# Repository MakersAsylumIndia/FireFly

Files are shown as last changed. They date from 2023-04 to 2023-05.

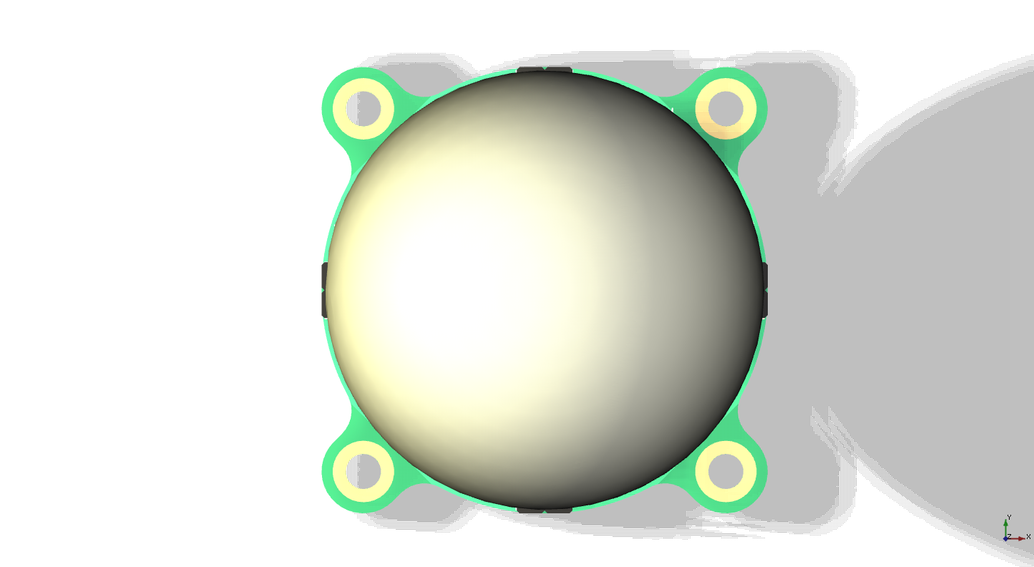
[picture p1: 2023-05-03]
fabricate/renders/firefly_v1_06.png

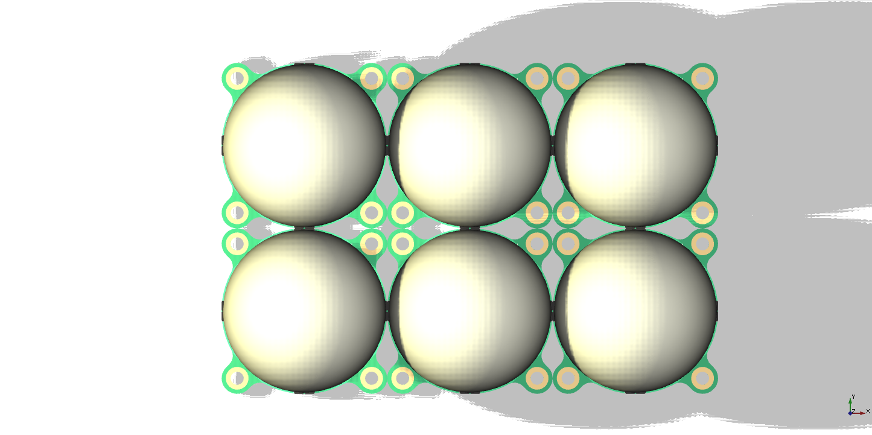
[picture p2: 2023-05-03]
fabricate/renders/firefly_v1_grid_02.png

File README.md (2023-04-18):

# FireFly
This circuit simulates a firefly with a tiny microcontroller. If put together with other fireflies, they will flash randomly. But after some time they will start to interact with each other and the flashes will start synchronize until all fireflies flash at once. Based on https://github.com/tinkerlog/fireflies

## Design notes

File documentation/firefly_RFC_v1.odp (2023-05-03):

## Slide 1

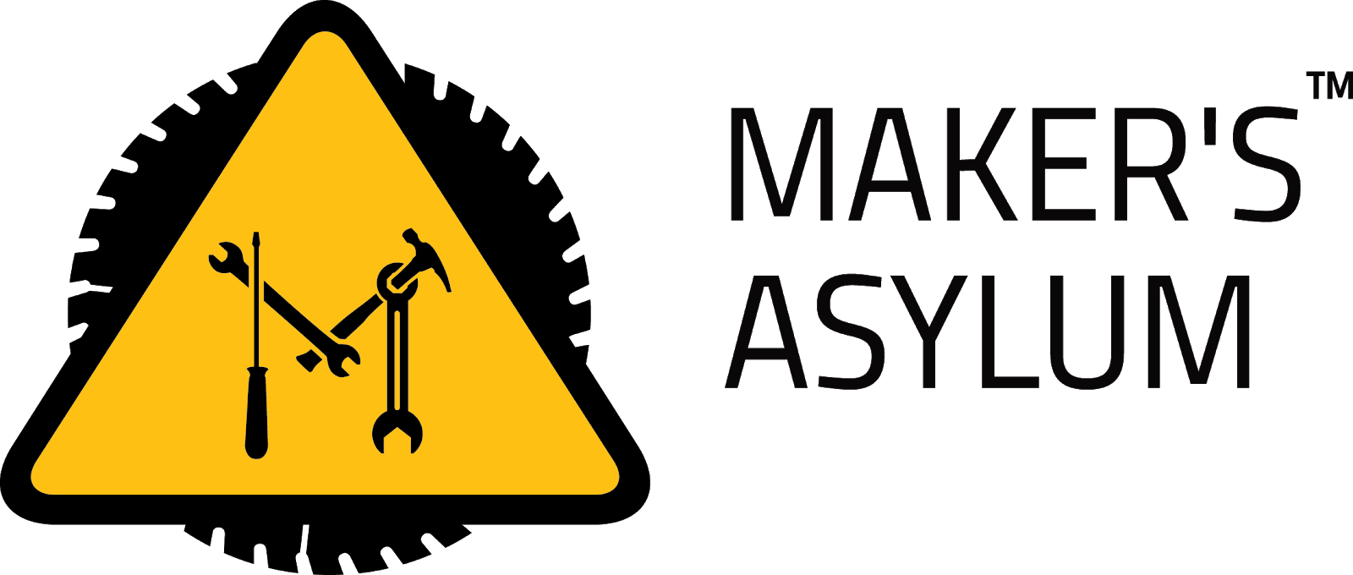
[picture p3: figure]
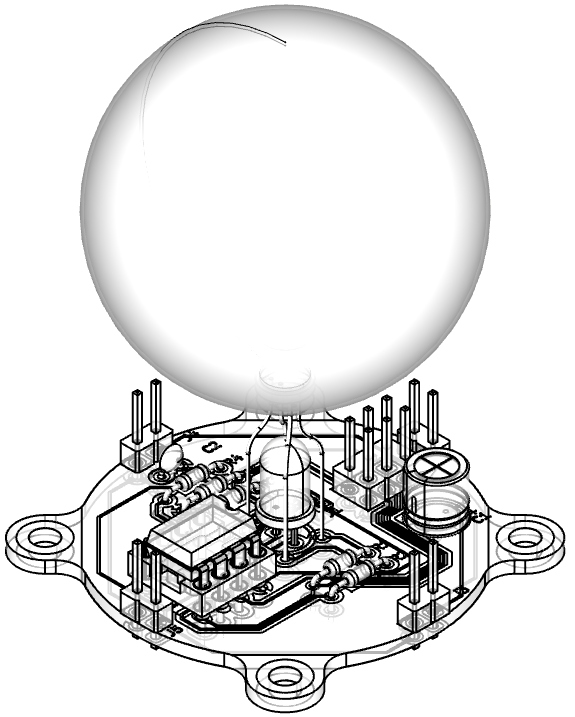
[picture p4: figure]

“FireFly” v1

Collaborative Art

Installation

(Proposed project for Innov School Practicum)

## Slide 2

Requirements

- Complexity level – between MODERATE and SIMPLE
- Must include elements of
  - Electronics (soldering)
  - Arduino (programming)
  - Rapid prototyping (3D printing / laser cutting)
  - Collaboration
- Powered by 5V – power bank, wall adapter, charger etc
- Expandable / Hackable

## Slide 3

Schematic

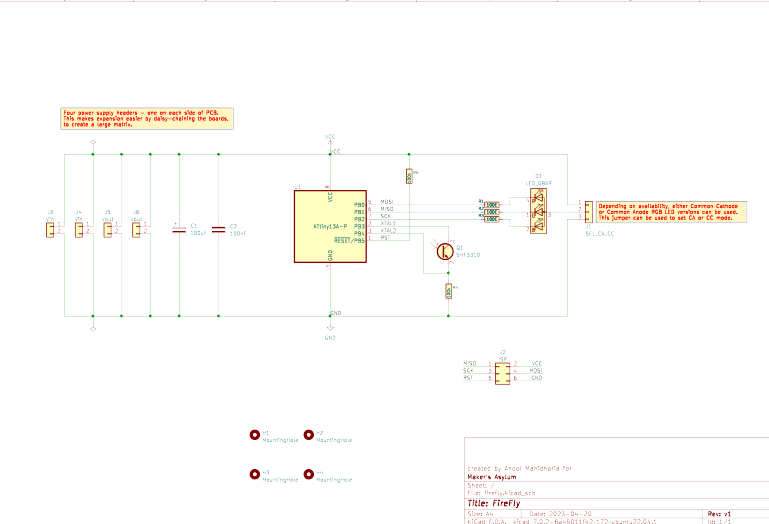
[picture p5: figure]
SVG Image created as firefly.svg date 2023/04/20 13:13:49 Image generated by Eeschema-SVG

Components:

- ATtiny13
- RGB LED, 5mm, CA/CC
- Light Sensor
- 5 resistors
- 2 capacitors
- Header pins
- Header pin shorting links
- PCB
- Ping-Pong ball

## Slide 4

Options

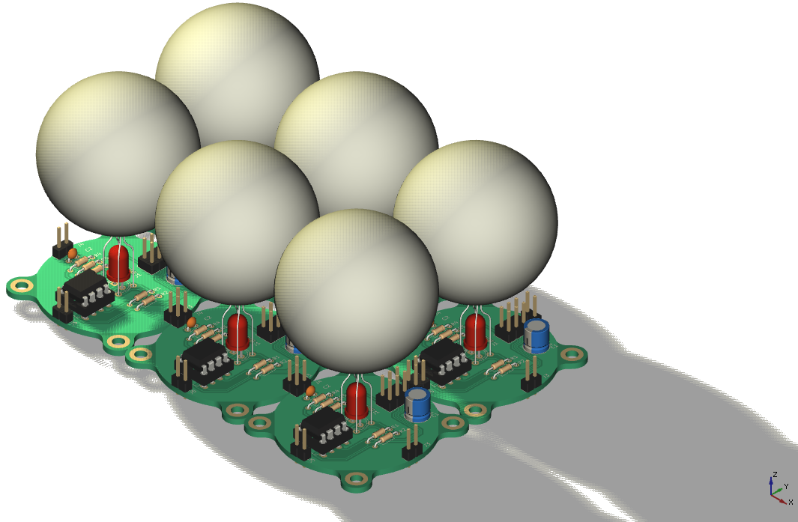
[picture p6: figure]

Optional upgrades

(not included in kit)

- The circuit is complete by itself, but this is a collaborative project.
- Multiple PCB’s are daisy chained together.
- Each flashes randomly, but after some time, they start synchronizing their color and flashing rate.
- The whole Practicum class can mount all their FireFlies on a MDF or Acrylic board.

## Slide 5

PCB Render

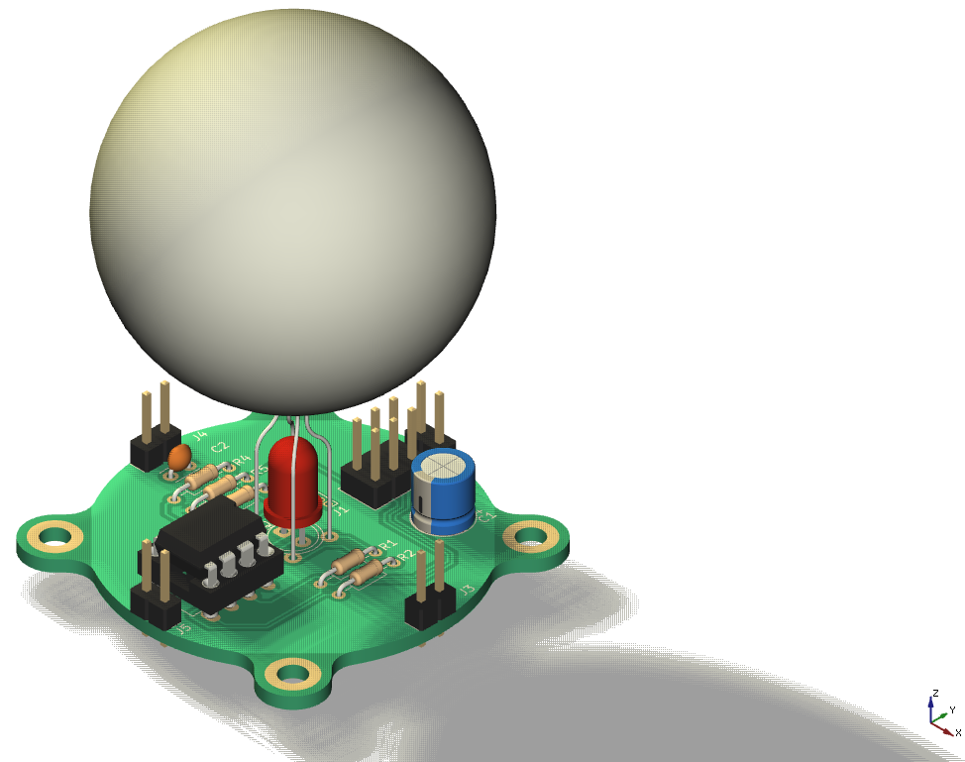
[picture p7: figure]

Power headers, x4

SPI header,

programming

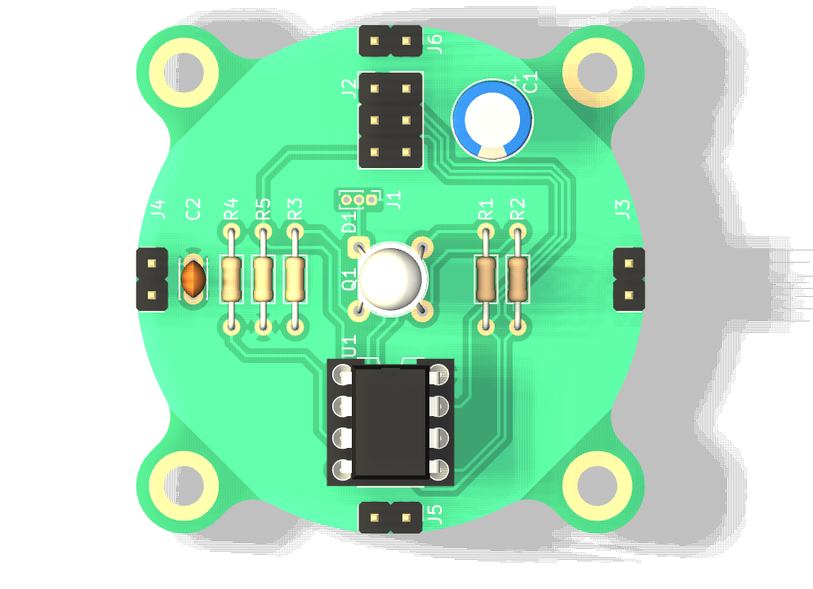
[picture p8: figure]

RGB LED

Ping-Pong Ball

diffuser

Light Sensor under RGB LED

ATtiny13

Mount holes

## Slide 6

PCB Front / Bottom view

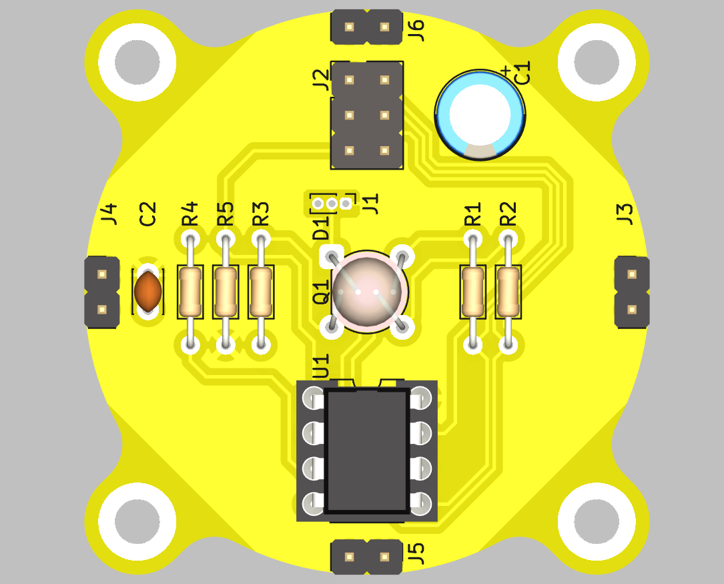
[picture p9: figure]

- All parts are mounted on front side.
- All parts are through hole so soldering is easy

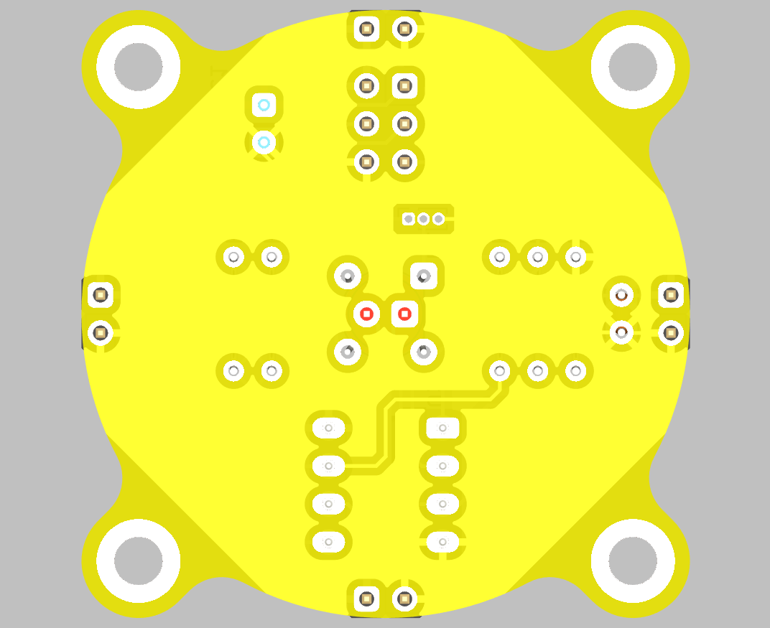
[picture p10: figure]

- Add some funky text / graphics on bottom

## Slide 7

PCB Side view

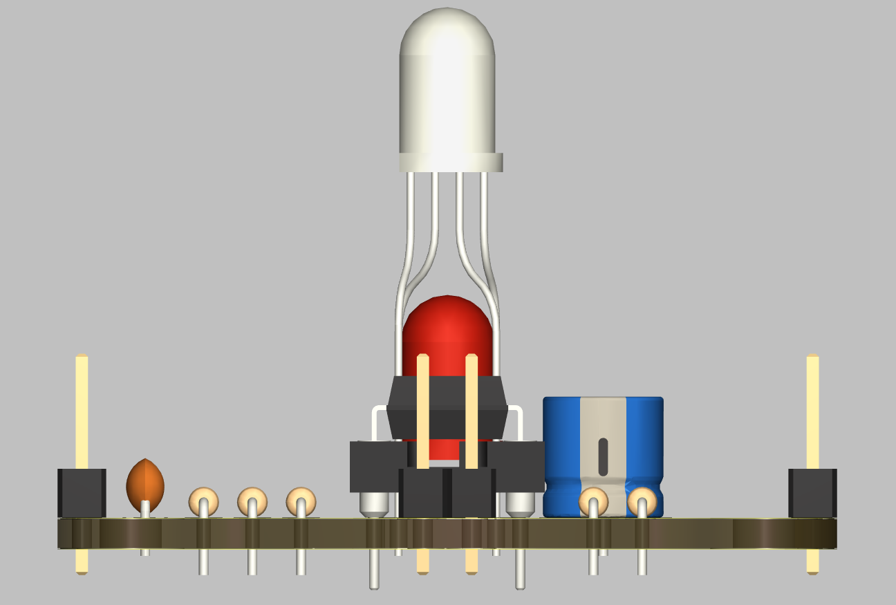
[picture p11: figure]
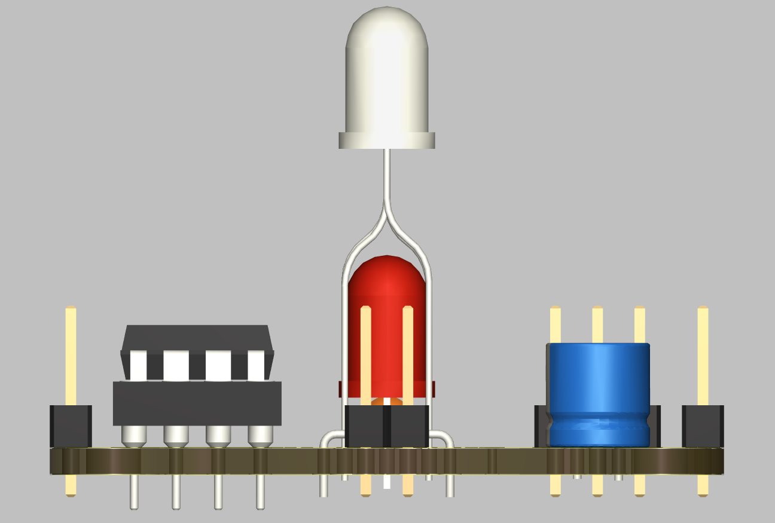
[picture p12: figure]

- Side views of the PCB.

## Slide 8

1.6” (40.6 mm)

1.6” (40.6 mm)

PCB dimensions

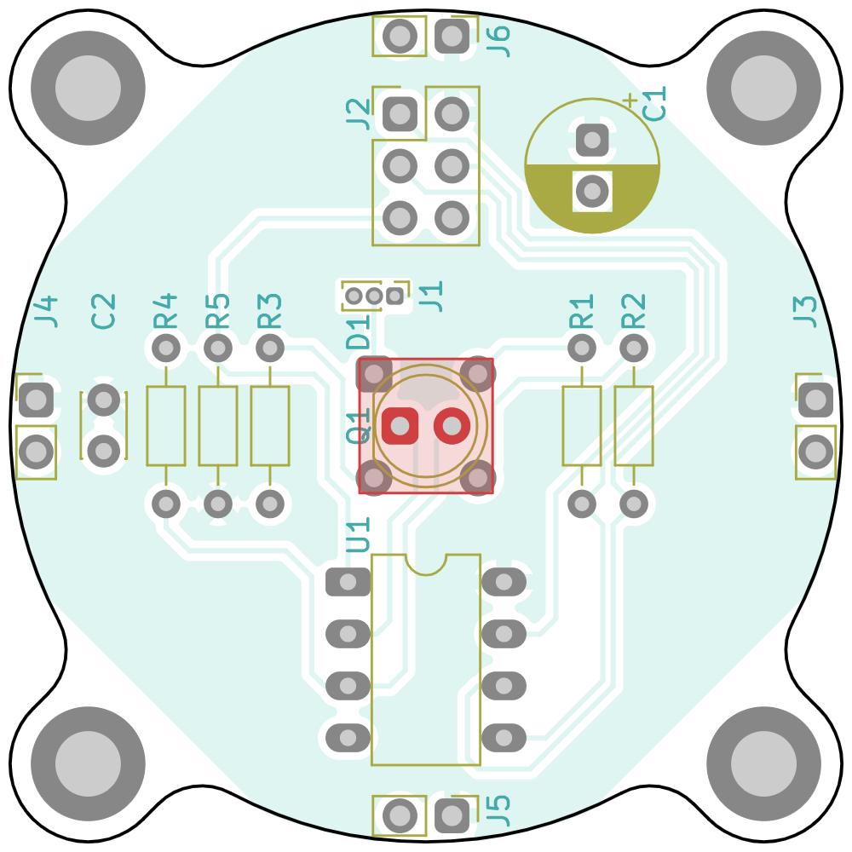
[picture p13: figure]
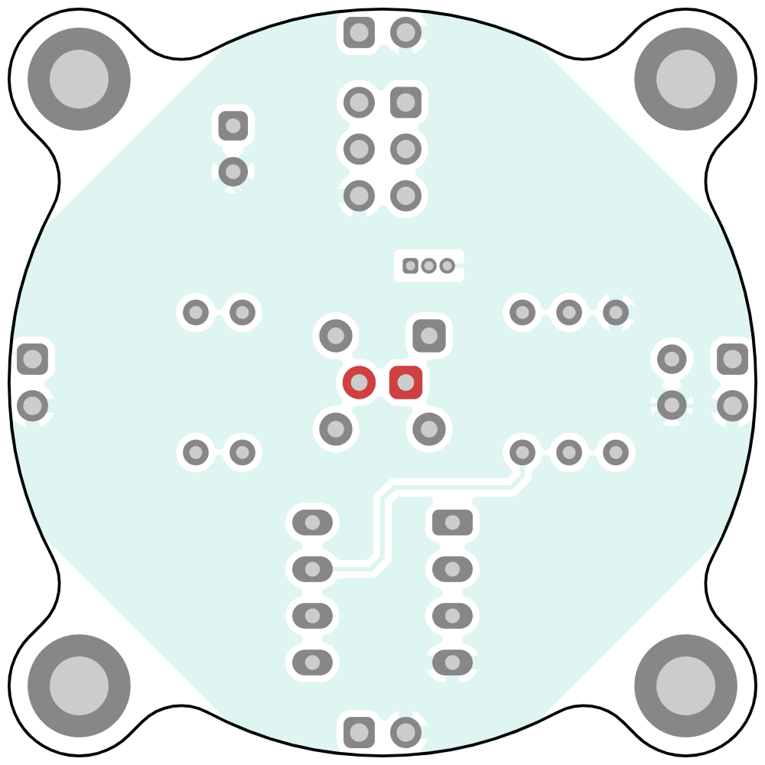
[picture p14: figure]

1.6 inches x 1.6 inches

(40.6 mm x 40.6 mm)

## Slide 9

Installation

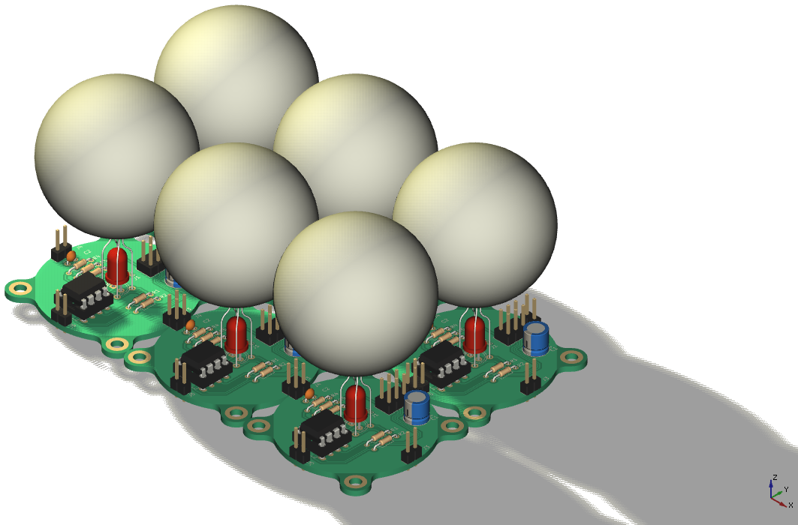
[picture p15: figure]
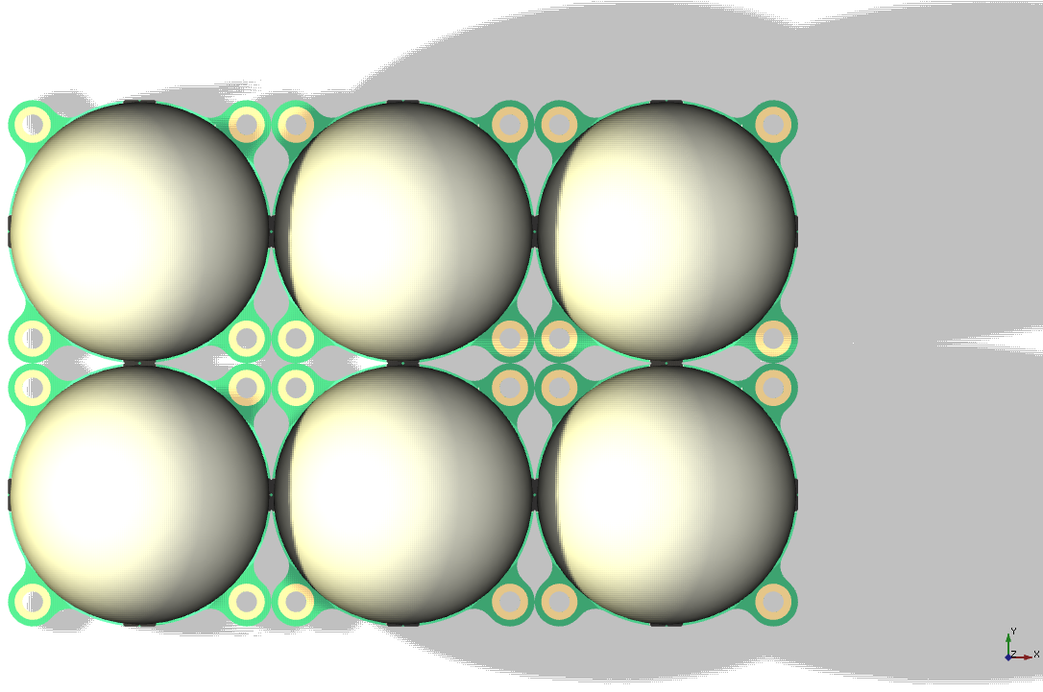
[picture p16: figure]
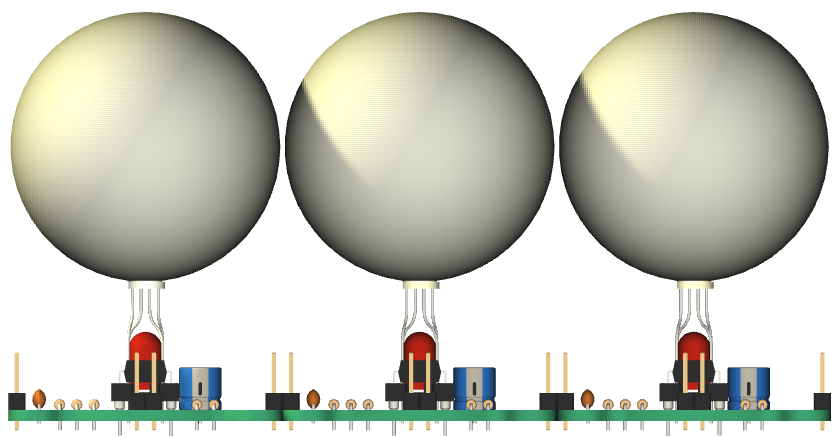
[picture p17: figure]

Individual PCB’s are connected to each other using header pin shorting links. Connections are just for power supply.

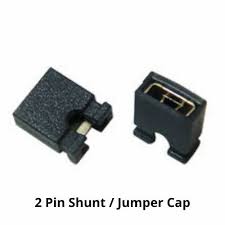
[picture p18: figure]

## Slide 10

NOTES

- Derived from:
  - https://www.instructables.com/Synchronizing-Fireflies/
  - https://tinkerlog.com/howto/synchronizing-firefly-how-to/
  - https://github.com/tinkerlog/fireflies
- Microcontroller is ATtiny13. Running Arduino on it will take some effort.
- Original code is available as a ‘Makefile”. This will have to be reverse engineered to work as Arduino code.
- More details on algorithm, code etc on the Instructables page

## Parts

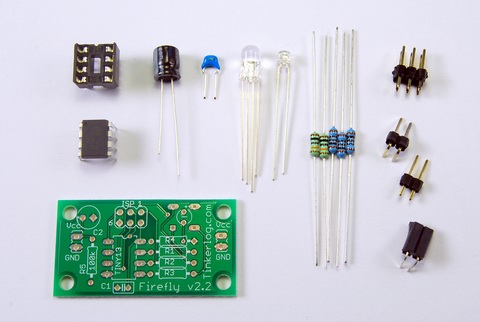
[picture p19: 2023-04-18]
datasheets/fireflies_parts.jpg

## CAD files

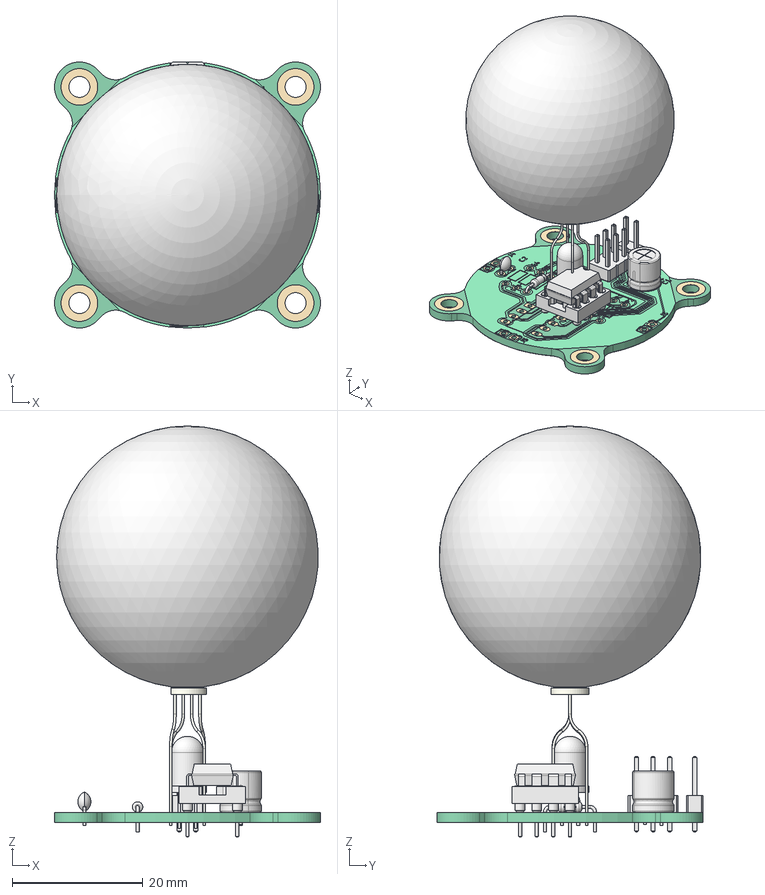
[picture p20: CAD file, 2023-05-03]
fabricate/firefly_v1_grid.FCStd
40.6 x 40.6 x 62.8 mm
DIP_8_W762mm_Socket_sp
DIP_8_W762mm_Socket_sp001
Pcb_3165
R3_R_Axial_DIN0204_L36mm_D16mm_P762mm_Horizontal_c94ef6852790
J6_PinHeader_1x02_P254mm_Vertical_1fb545e78c9a
J2_PinHeader_2x03_P254mm_Vertical_75255a230ba9
C1_CP_Radial_D63mm_P250mm_7c2f516e95ce
Q1_LED_D5.0mm_18f4e428e7b4
C2_C_Disc_D30mm_W20mm_P250mm_075f2212bfdc
topTracks_3165
botTracks_3165
topPads_3165
botPads_3165
topSilks_3a64
topZones_3165
botZones_3165

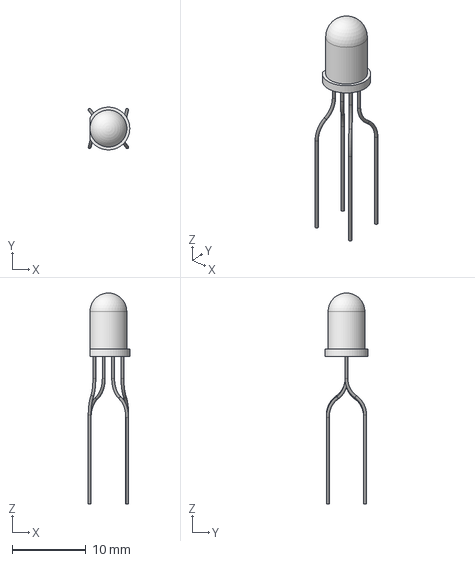
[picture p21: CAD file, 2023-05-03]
fabricate/footprints/LED_5mm_RGB-Fusion.step
5.65 x 5.79 x 28.6 mm

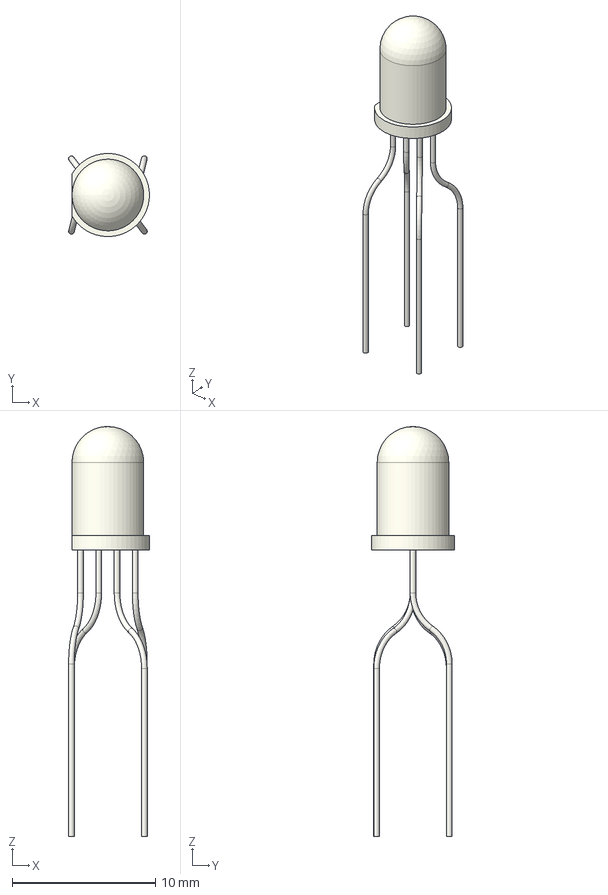
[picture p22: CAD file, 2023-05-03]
kicad_v1/firefly/3d_models/LED_D5.0mm-4_RGB_Square_Pins.step
5.65 x 5.79 x 28.6 mm

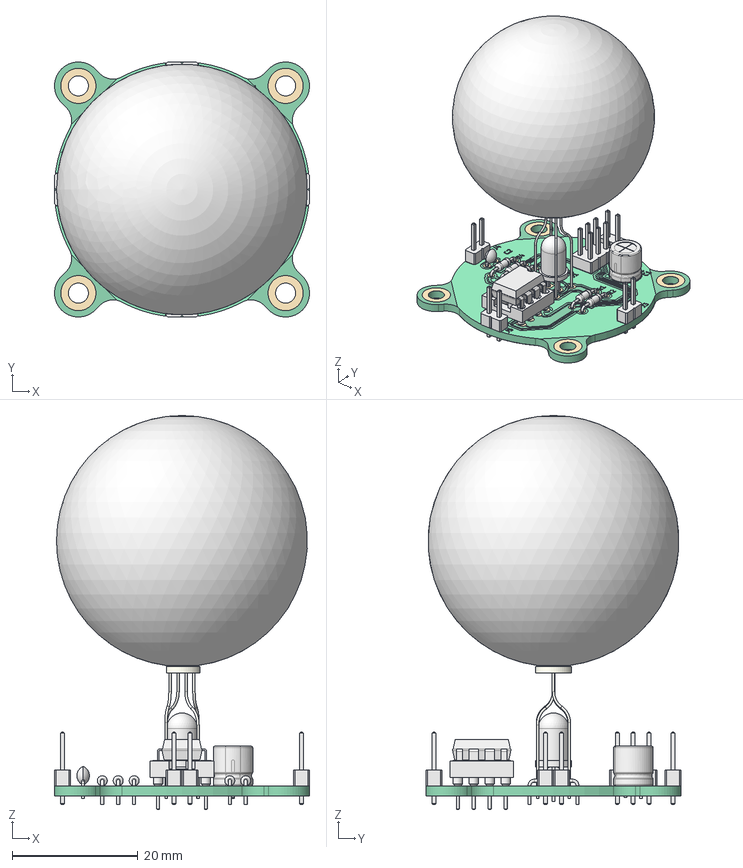
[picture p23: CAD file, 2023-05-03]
fabricate/firefly_v1.FCStd
40.6 x 40.6 x 62.8 mm
Pcb_3165
topPads_3165
topTracks_3165
topZones_3165
botPads_3165
botTracks_3165
botZones_3165
topSilks_3a64
R3_R_Axial_DIN0204_L36mm_D16mm_P762mm_Horizontal_c94ef6852790 x 5
J6_PinHeader_1x02_P254mm_Vertical_1fb545e78c9a x 4
J2_PinHeader_2x03_P254mm_Vertical_75255a230ba9
C1_CP_Radial_D63mm_P250mm_7c2f516e95ce
DIP_8_W762mm_Socket_sp
DIP_8_W762mm_Socket_sp001
Q1_LED_D5.0mm_18f4e428e7b4
C2_C_Disc_D30mm_W20mm_P250mm_075f2212bfdc

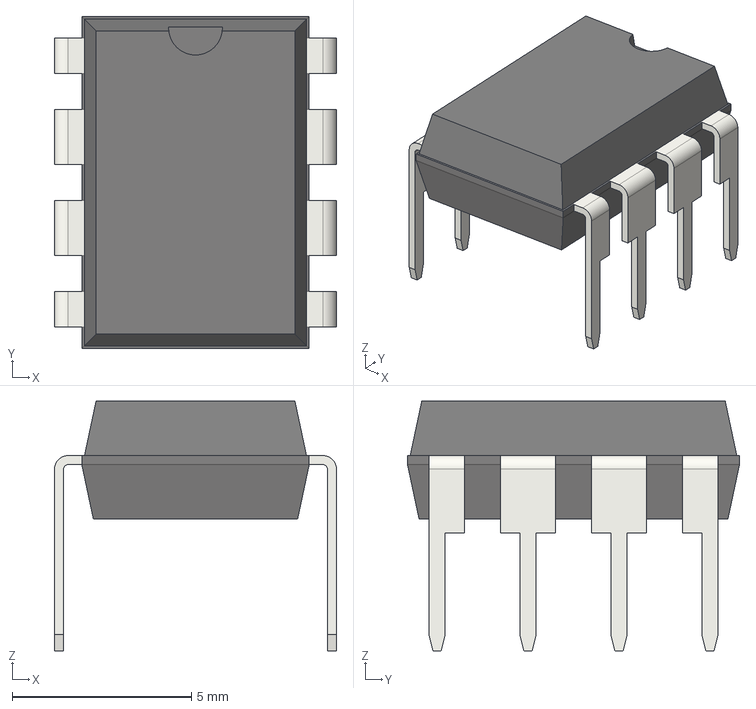
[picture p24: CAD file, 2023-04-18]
kicad_v1/firefly/3d_models/DIP-8_W7.62mm.step
7.87 x 9.27 x 6.98 mm

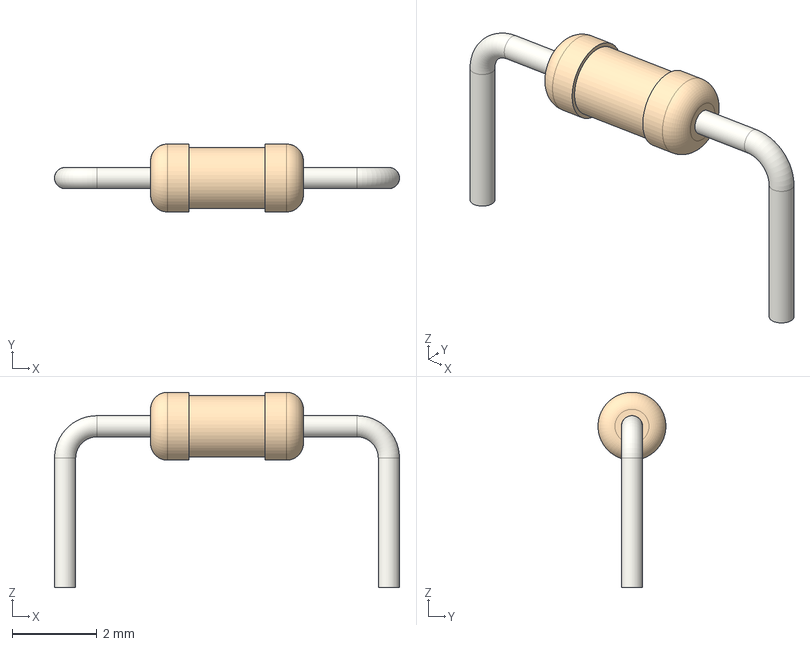
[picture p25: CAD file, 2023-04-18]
kicad_v1/firefly/3d_models/R_Axial_DIN0204_L3.6mm_D1.6mm_P7.62mm_Horizontal.step
8.12 x 1.60 x 4.60 mm

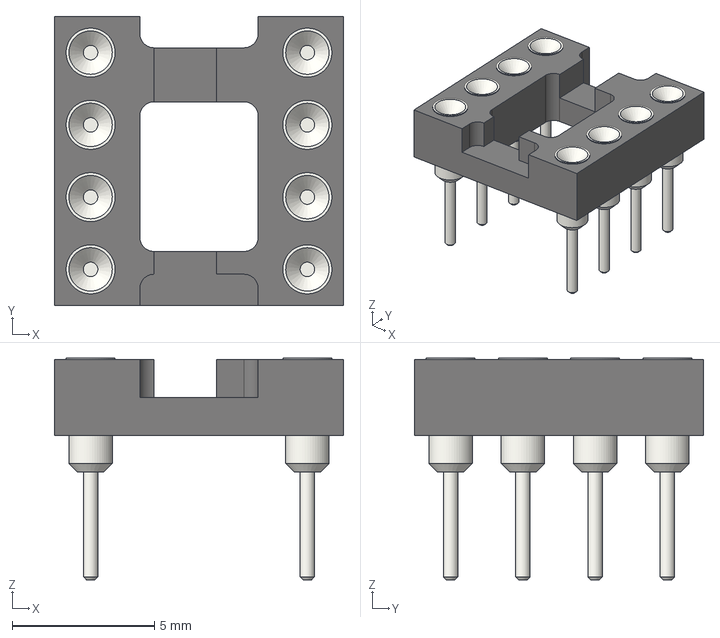
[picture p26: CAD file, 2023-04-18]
kicad_v1/firefly/3d_models/DIP-8_W7.62mm_Socket.step
10.2 x 10.2 x 7.79 mm

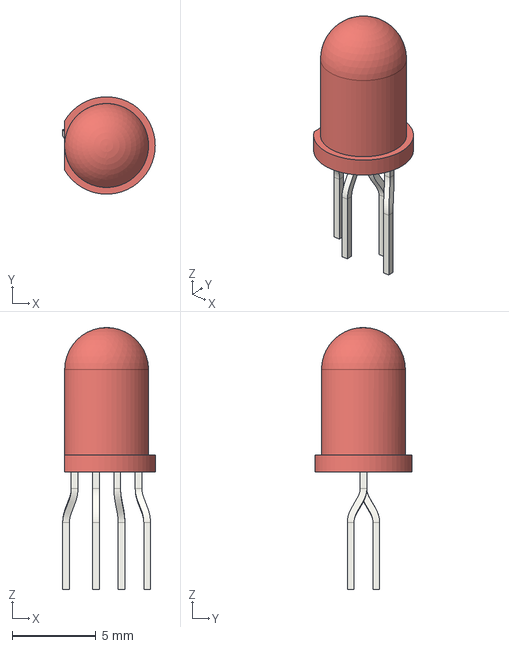
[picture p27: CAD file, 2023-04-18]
kicad_v1/firefly/3d_models/LED_D5.0mm-4_RGB_Staggered_Pins.step
5.51 x 5.79 x 15.6 mm

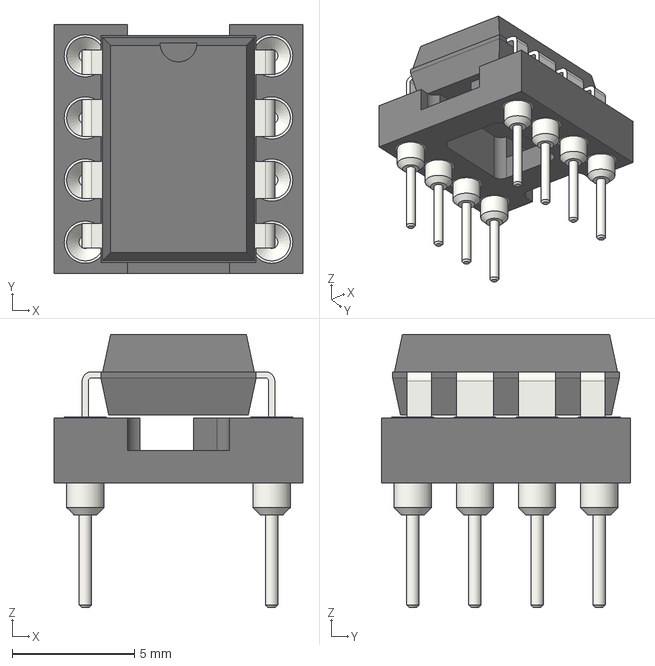
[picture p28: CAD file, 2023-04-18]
kicad_v1/firefly/3d_models/DIP_8_W762mm_Socket_chip.step
10.2 x 10.2 x 11.2 mm

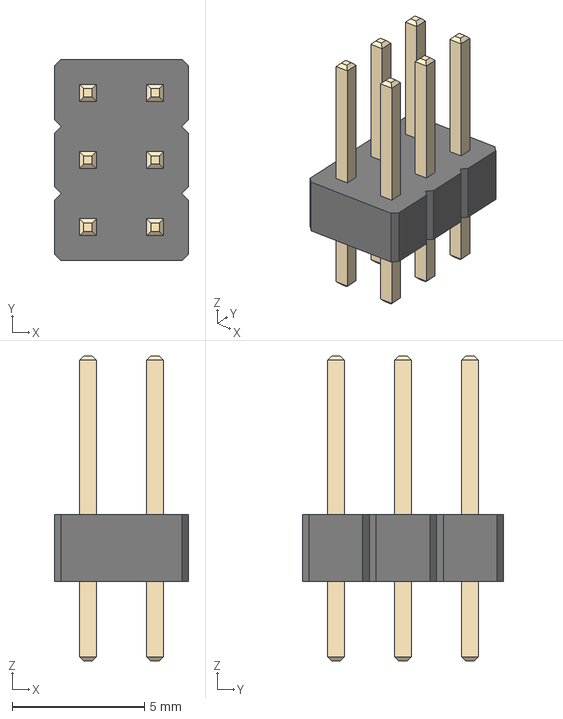
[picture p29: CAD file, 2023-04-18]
kicad_v1/firefly/3d_models/PinHeader_2x03_P2.54mm_Vertical.step
5.08 x 7.62 x 11.5 mm

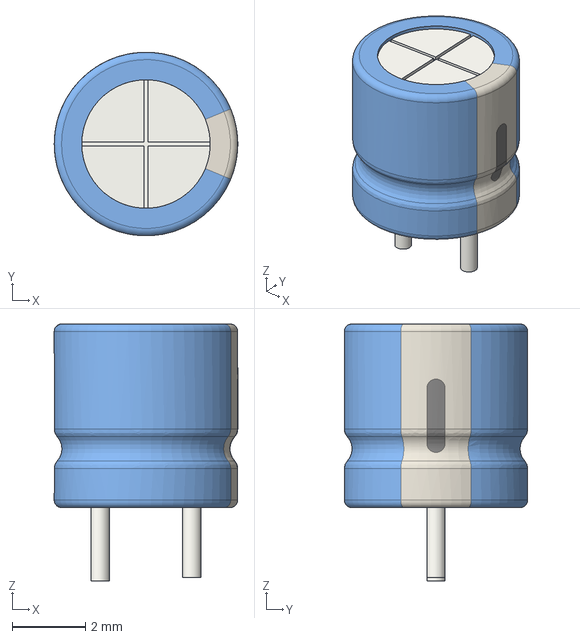
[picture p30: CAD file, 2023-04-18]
kicad_v1/firefly/3d_models/CP_Radial_D5.0mm_P2.50mm.step
5.00 x 5.00 x 7.00 mm

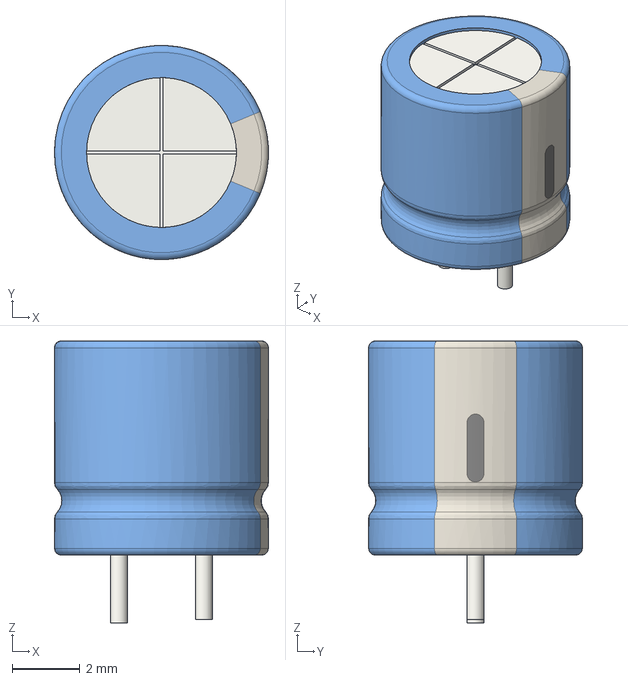
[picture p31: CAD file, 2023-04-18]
kicad_v1/firefly/3d_models/CP_Radial_D6.3mm_P2.50mm.step
6.30 x 6.30 x 8.30 mm

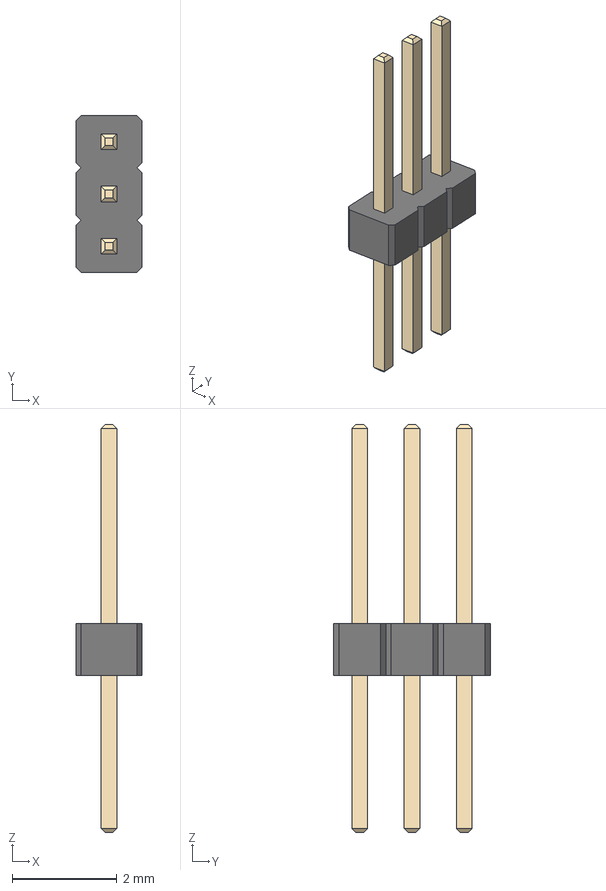
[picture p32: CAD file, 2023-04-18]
kicad_v1/firefly/3d_models/PinHeader_1x03_P1.00mm_Vertical.step
1.27 x 3.00 x 7.80 mm

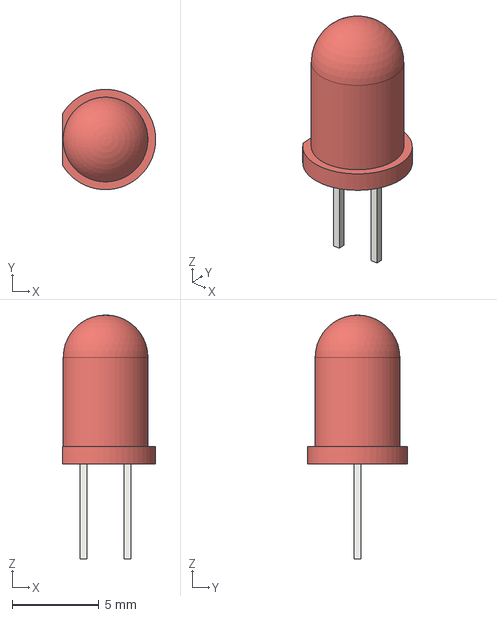
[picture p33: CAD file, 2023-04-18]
kicad_v1/firefly/3d_models/LED_D5.0mm.step
5.40 x 5.79 x 14.1 mm

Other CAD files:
fabricate/footprints/LED_5mm_RGB.step
kicad_v1/firefly/3d_models/C_Disc_D3.0mm_W2.0mm_P2.50mm.step
kicad_v1/firefly/3d_models/LED_D5.0mm-4_RGB_Staggered_Pins_raise.step
kicad_v1/firefly/3d_models/PinHeader_1x02_P2.54mm_Vertical.step
fabricate/footprints/LED_5mm_RGB.FCStd
kicad_v1/firefly/firefly-B_Silkscreen.dxf
kicad_v1/firefly/firefly-F_Silkscreen.dxf

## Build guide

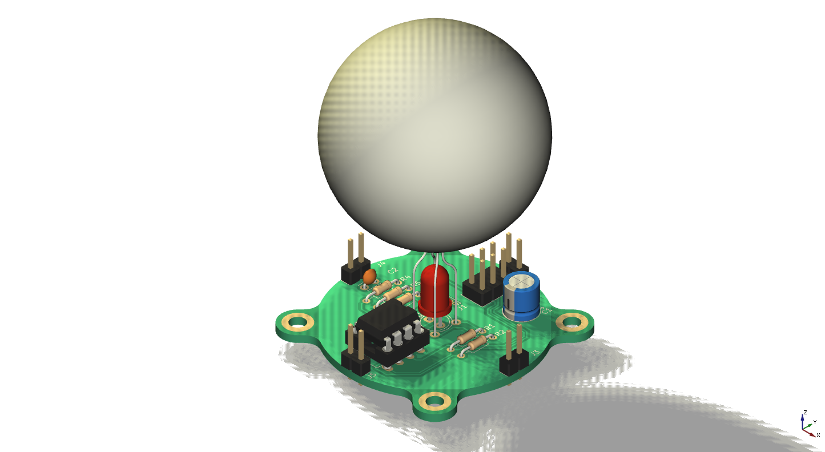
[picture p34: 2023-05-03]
fabricate/renders/firefly_v1_05.png

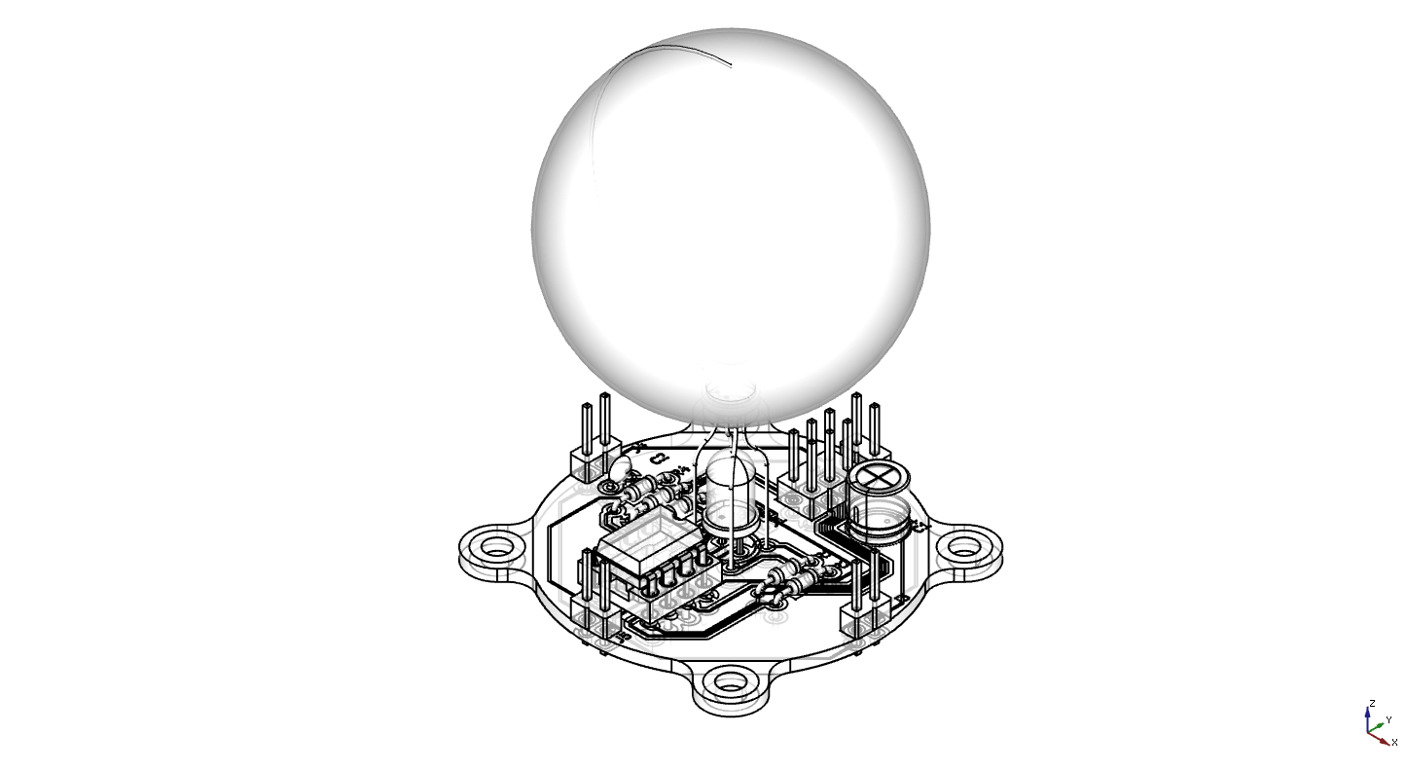
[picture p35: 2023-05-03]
fabricate/renders/firefly_v1_08.png

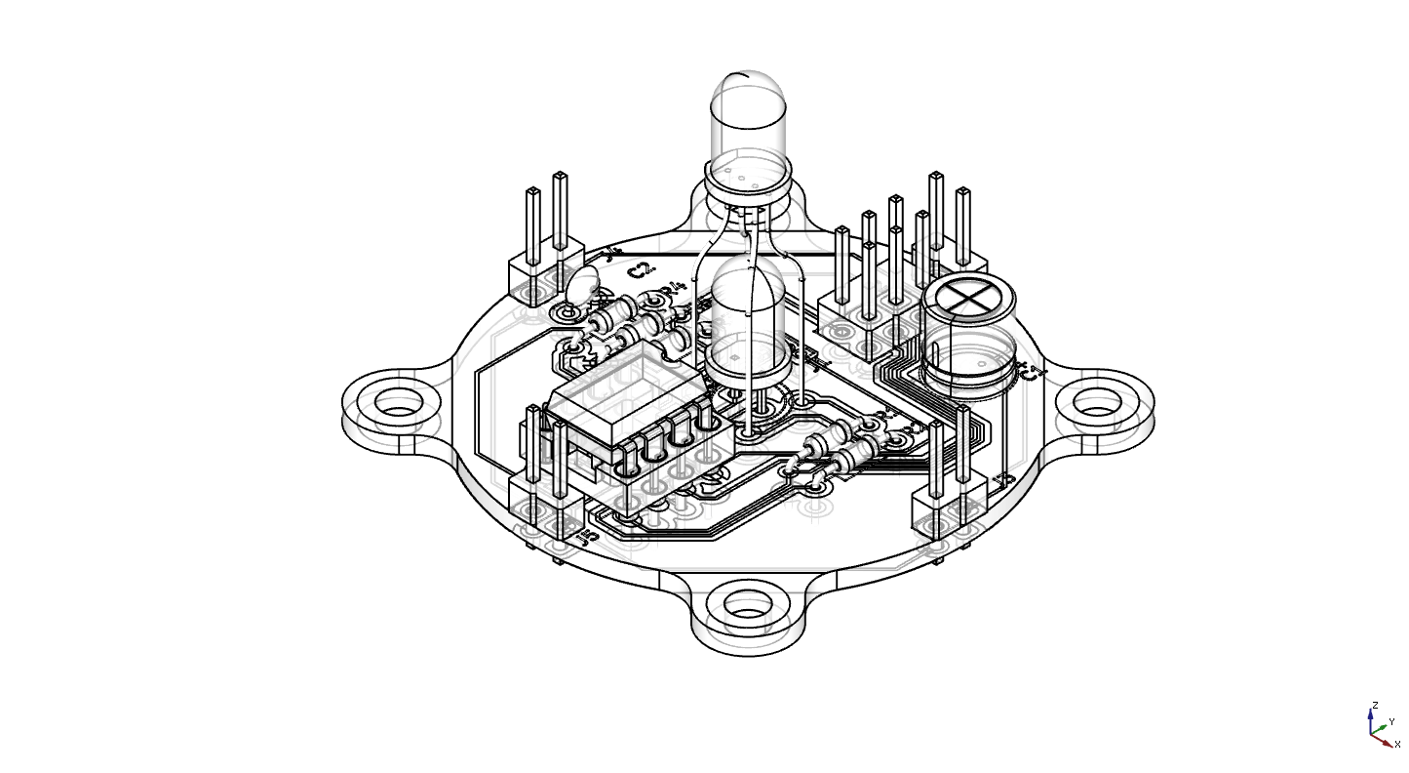
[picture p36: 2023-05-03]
fabricate/renders/firefly_v1_04.png

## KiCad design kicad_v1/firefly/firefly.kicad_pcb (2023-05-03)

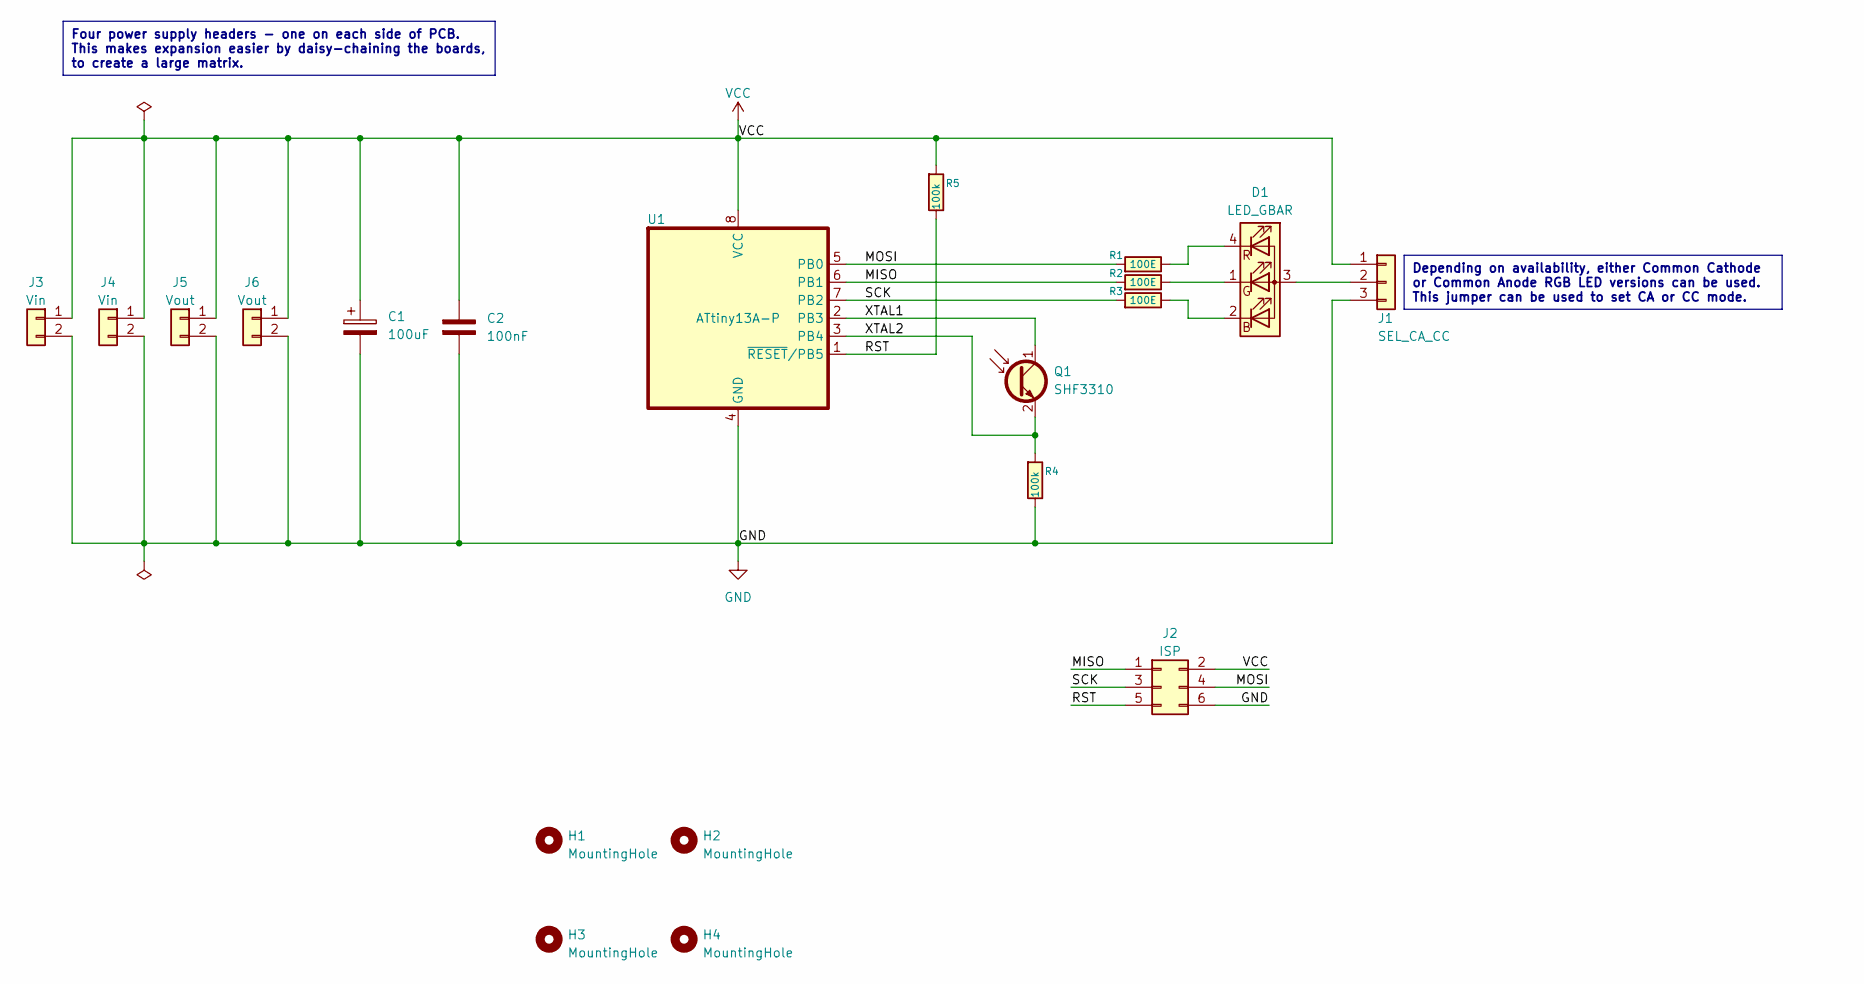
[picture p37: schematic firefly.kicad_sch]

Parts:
C1: 100uF; CP_Radial_D6.3mm_P2.50mm
C2: 100nF; C_Disc_D3.0mm_W2.0mm_P2.50mm
D1: LED_GBAR; LED_D5.0mm-4_RGB_square_Pins
H1, H2, H3, H4: MountingHole; MountingHole_3.2mm_M3_DIN965_Pad
J1: SEL_CA_CC; PinHeader_1x03_P1.00mm_Vertical
J2: ISP; PinHeader_2x03_P2.54mm_Vertical
J3, J4: Vin; PinHeader_1x02_P2.54mm_Vertical
J5, J6: Vout; PinHeader_1x02_P2.54mm_Vertical
Q1: SHF3310; LED_D5.0mm
R1, R2, R3: 100E; R_Axial_DIN0204_L3.6mm_D1.6mm_P7.62mm_Horizontal
R4, R5: 100k; R_Axial_DIN0204_L3.6mm_D1.6mm_P7.62mm_Horizontal
U1: ATtiny13A-P; DIP-8_W7.62mm_oval

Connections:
/MISO: J2.1, R2.1, U1.6 (PB1)
/MOSI: J2.4, R1.1, U1.5 (PB0)
/RST: J2.5, R5.2, U1.1 (~RESET/PB5)
/SCK: J2.3, R3.1, U1.7 (PB2)
/XTAL1: Q1.1 (C), U1.2 (PB3)
/XTAL2: Q1.2 (E), R4.1, U1.3 (PB4)
GND: C1.2, C2.2, J1.3, J2.6, J3.2, J4.2, J5.2, J6.2, R4.2, U1.4 (GND)
unnamed: D1.3 (A), J1.2
unnamed: D1.2 (BK), R3.2
unnamed: D1.1 (GK), R2.2
unnamed: D1.4 (RK), R1.2
VCC: C1.1, C2.1, J1.1, J2.2, J3.1, J4.1, J5.1, J6.1, R5.1, U1.8 (VCC)

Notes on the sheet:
Four power supply headers - one on each side of PCB. This makes expansion easier by daisy-chaining the boards, to create a large matrix.
Depending on availability, either Common Cathode or Common Anode RGB LED versions can be used. This jumper can be used to set CA or CC mode.

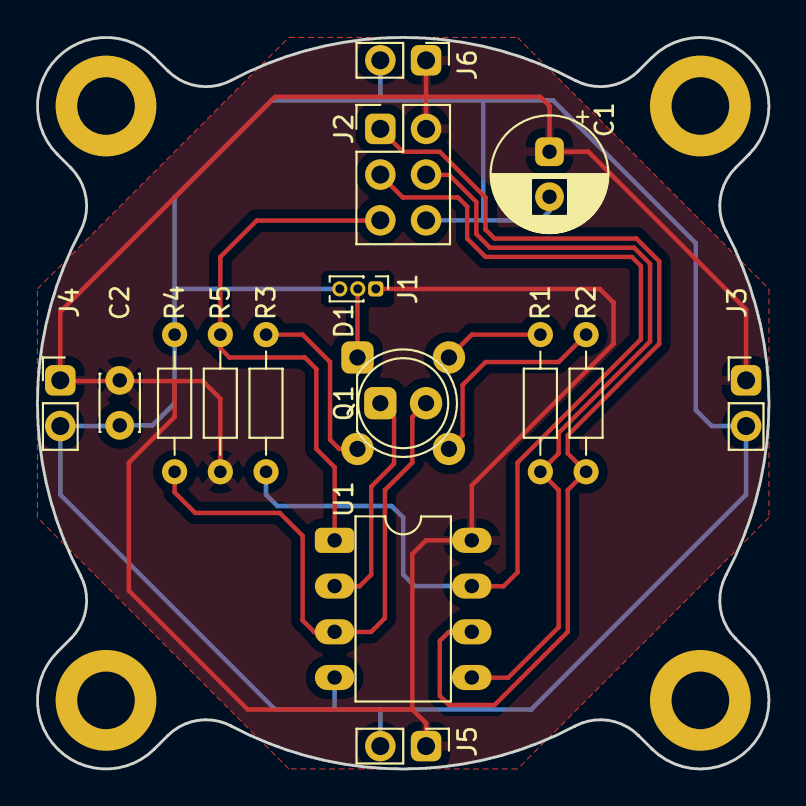
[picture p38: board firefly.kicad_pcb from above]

Board: 2 copper layers, 40.6 x 40.6 mm, 20 parts (0 on the bottom side), 12 nets.

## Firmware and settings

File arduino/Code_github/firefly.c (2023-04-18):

/* -----------------------------------------------------------------------
 * Title:    firefly.c
 * Author:   Alexander Weber <alex@tinkerlog.com>
 *           http://tinkerlog.com
 * Date:     13.05.2008
 * Hardware: ATtiny13v
 * Reference:
 *   HSV-to-RGB conversion based on Tod E. Kurt's version.
 *   http://todbot.com/projects/smart-leds/softpwm_t13/softpwm_t13.c
 *
 * Description
 * This tiny program simulates a single firefly. It uses an RGB-LED to flash
 * once every two seconds. If put together with other fireflies, it uses a
 * light sensor (a photo transistor) to detect flashes from other fireflies
 * nearby. The program tries to synchronize its own flash with the flash of
 * its neighbours.
 * 
 *
 * The RGB-LED is a commond cathode type.
 *
 *   Vcc   o     ATtiny13V               o Vcc (+5V)
 *         |    +--------v--------+     | 
 *        100k  |                 |     |
 *         +----+ 1 PB5     Vcc 8 +-----+
 *              |                 |
 *         +----+ 2 PB3     PB2 7 +-- 100R --|>|--+  Green
 *  phototrans. |                 |               |
 *         +----+ 3 PB4     PB1 6 +-- 100R --|>|--+  Red
 *         R4   |                 |               |
 *         +----+ 4 GND     PB0 5 +-- 100R --|>|--+  Blue
 *         |    |                 |               |
 *         |    +-----------------+               |
 *         |                                      |
 *        _|_                                    _|_
 *
 * R4 has to be adjusted to the used LDR (1k-50k).
 * If you use a phototransistor, try higher values (>=100k). 
 *
 */

#include <avr/io.h>
#include <avr/interrupt.h>
#include <util/delay.h>

#define FLASH_POWER 8000      // power level at which the firefly flashes
#define POWER_BOOST 400       // amount of power to add, for every other flash
#define FLASH_DELAY 200       // how long lasts the flash
#define DAYLIGHT 240          // values higher than that are recognized as daylight
#define DAYLIGHT_DELAY 10000  // wait 10 seconds, if daylight detected
#define BLIND_AFTER_OTHER 800 // how long are we blind after another flash
#define BLIND_AFTER_SELF 100  // how long are we blind after our own flash
#define THRESHOLD_DELTA 20    // added to the ambient light value


// #define NEW_RGB // use this to choose different leds pins

#ifdef NEW_RGB
#define B_BIT 0               // pin 5  -- LED pin 2
#define R_BIT 1               // pin 6  -- LED pin 4
#define G_BIT 2               // pin 7  -- LED pin 1
#else
#define R_BIT 0               // pin 5  -- LED pin 2
#define B_BIT 1               // pin 6  -- LED pin 4
#define G_BIT 2               // pin 7  -- LED pin 1
#endif


static volatile uint8_t act_light = 0;  // value for lightness
static uint8_t softscale = 0; // used to prescale the timer 
static volatile uint8_t r = 0;         // rgb, set these to control the color
static volatile uint8_t g = 0;         // green
static volatile uint8_t b = 0;         // blue
static uint8_t rtmp = 0;      // tmp vars for rgb, do not use directly
static uint8_t gtmp = 0;      
static uint8_t btmp = 0;      



/* -----------------------------------------------------
 * ADC interrupt
 * The AD conversion is in free running mode.
 * -> prescaler 128 -> 75.000 samples at 9.600.000 Hz
 */
SIGNAL(ADC_vect) {
  act_light = ADCH;           // read only 8-bit
}



/* -----------------------------------------------------
 * Timer0 overflow interrupt
 * F_CPU 9.600.000 Hz 
 * -> prescaler 0, overrun 256 -> 37.500 Hz 
 * -> 256 steps -> 146 Hz
 *
 * Read global rgb and save it to tmp vars and decide, to switch
 * on R, G or B. 
 * Range is for rgb is 0-255 (dark to full power)
 */
SIGNAL(TIM0_OVF_vect) {	
  // every 256th step take over new values
  if (++softscale == 0) {    
    rtmp = r;
    gtmp = g;
    btmp = b;
    // check if switch on r, g and b
    if (rtmp > 0) {        
      PORTB |= (1 << R_BIT);
    } 
    if (gtmp > 0) {
      PORTB |= (1 << G_BIT);
    } 
    if (btmp > 0) {
      PORTB |= (1 << B_BIT);
    } 
  }
  // check if switch off r, g and b
  if (softscale == rtmp) {     
    PORTB &= ~(1 << R_BIT);
  }
  if (softscale == gtmp) {
    PORTB &= ~(1 << G_BIT);
  }
  if (softscale == btmp) {
    PORTB &= ~(1 << B_BIT);
  }
}



/* -----------------------------------------------------
 * Converts a hue into rgb values (HSV -> RGB). We are using
 * the HSV model, because there the color is directly related
 * to a single value, the hue and not three values as in RGB.
 * That makes it really easy to change the color from red to blue.
 * Even a full cycle (all rainbow colors) would be easy. You would
 * just increment this hue and don't have to deal with R, G and B.
 *
 * You can take a look at http://en.wikipedia.org/wiki/HSL_and_HSV
 * for how the HSV color model works. 
 * 
 * Normally the HSV model needs a full circle (360°) to distribute
 * all rainbow colors over this circle. But 360 is too big for a
 * single byte. So we use a small trick here. We DEFINE simply,
 * that our circle has only 252°, not 360°. Also 252 is dividable 
 * by 6 and in the HSV model we have 6 segments. In every segment
 * two values of R, G and B stays constant (0 or 252) and another
 * value ramps up or down.
 *
 * Here is a small table with all colors. Segments stands for
 * the color segment. Color, ok that's obvious. Hue is the 
 * hue from 0° to 360°. Hue(252) stands for the hue, that we are
 * using, from 0° to 252°.
 *
 * Segment - Color     - hue - hue(252)
 *       0 - red       -   0 -   0
 *       1 - yellow    -  60 -  42
 *       2 - green     - 120 -  84
 *       3 - turquoise - 180 - 126
 *       4 - blue      - 240 - 168
 *       5 - pink      - 300 - 210
 *       0 - red       - 360 - 252
 */
void h_to_rgb(uint8_t hue) {
  uint8_t hd = hue / 42;      // 42 == 252/6, determines the segment this hue lies in
  uint8_t hi = hd % 6;        // gives 0-5, to be sure even if hd was greater than 5.
                              // Our segments are 0-5.
  uint8_t f = hue % 42;       // Calculates the hue within the segment. This value is
                              // used for the color ramp up or down. 
  uint8_t fs = f * 6;         // The hue within the segment can only be 0-42, but we 
                              // need 0..252 for our color, so we multiply by 6.
  switch (hi) {
  case 0:
    r = 252;     //   red: full power
    g = fs;      // green: ramp up
    b = 0;       //  blue: off
    break;
  case 1:
    r = 252-fs;  //   red: ramp down
    g = 252;     // green: full power
    b = 0;       //  blue: off
    break;
  case 2:
    r = 0;       //   red: off
    g = 252;     // green: full power
    b = fs;      //  blue: ramp up
    break;
  case 3:
    r = 0;       //   red: off
    g = 252-fs;  // green: ramp down
    b = 252;     //  blue: full power
    break;
  case 4:
    r = fs;      //   red: ramp up
    g = 0;       // green: off
    b = 252;     //  blue: full power
    break;
  case 5:
    r = 252;     //   red: full power
    g = 0;       // green: off
    b = 252-fs;  //  blue: ramp down
    break;
  }
}



int main(void) {	
	
  uint8_t i = 0;              // used for loops
  uint8_t light = 0;          // current lightness
  uint8_t nervous = 0;        // value for how nervous we are. 0 to 168. 
  uint16_t threshold = 0;     // threshold to determine a flash
  uint16_t power = 0;         // current power level
  uint16_t blind = 0;         // stores for how many cycles we are blind
  uint16_t flash_power = FLASH_POWER;  // if power is > flash_power, then flash
	
  // enable pins as output
  DDRB |= 
    (1 << PB3) |              // PB3 acts as power supply for photo transistor voltage divider
    (1 << R_BIT) |            // R
    (1 << G_BIT) |            // G
    (1 << B_BIT);             // B

  // power on the voltage divider
  PORTB |= (1 << PB3);	
			
  // timer 0 setup, prescaler none
  TCCR0B |= (0 << CS02) | (0 << CS01) | (1 << CS00);

  // enable timer 0 interrupt
  TIMSK0 |= (1 << TOIE0);	

  // enable adc
  ADCSRA |= 
    (1 << ADEN) |             // enable ADC
    (1 << ADATE) |            // enable auto triggering
    (1 << ADIE) |             // enable ADC interrupt
    (1 << ADSC) |             // start conversion
    (1 << ADPS2) | (1 << ADPS1) | (1 << ADPS0);  // prescaler 128 --> 75k samples at 9.6 MHz

  // select ADC channel
  ADMUX |= 
    (0 << REFS0) |            // select Vcc as reference
    (1 << ADLAR) |            // ADC output as 8-bit, left adjusted
    (1 << MUX1);              // select channel 2, pin 3

  // enable all interrupts
  sei();

  // intro, blink red 5 times
  for (i = 0; i < 5; i++) {
    r = 255;
    _delay_ms(100);
    r = 0;
    _delay_ms(100);
  }


  // compute threshold of the ambient light
  for (i = 0; i < 4; i++) {
    threshold += act_light;
    _delay_ms(500);
  }	
  threshold = threshold >> 2;       // divides by 4
  threshold += THRESHOLD_DELTA;     // move the threshold above the ambient average

  // try to sleep some randomized time
  i = (act_light & 0x03);           // use the last (right most) 2 bits of the actual lightness
  while (i--) {
    _delay_ms(1000);
  }

  // enter the main loop
  while (1) {

    _delay_us(500);                 // every cylce takes at least 0.5 ms

    if (power > 6000) {             // increase the power level with a, first fast ascending,
      power += 1;                   // later slower ascending, function
    }
    else if (power > 4000) {
      power += 2;
    }
    else if (power > 3000) {
      power += 4;
    }
    else if (power > 2000) {
      power += 8;
    }
    else {
      power += 16;
    }

    light = act_light;              // read the actual lightness
    if (!blind) {                   
      if (light > DAYLIGHT) {	    // if we detect daylight, then it's too bright to work
	g = 32;                     // switch color to green
        _delay_ms(DAYLIGHT_DELAY);  // and wait 10 seconds
	g = 0;                      
      }
      else if (light > threshold) { // was it a flash?
	// if the flash comes in, when we are in between 2000 and 7000, then we detect
	// the flash as not in sync and increase the nervous level ...
	if ((power > 2000) && (power < 7000)) {
	  nervous = (nervous >= 158) ? 168 : (nervous + 10);
	}
	else {
	  if (nervous > 5) {        // ... otherwise decrease it
	    nervous -= 5;
	  }
	}
        power += POWER_BOOST;       // boost the power
        blind = BLIND_AFTER_OTHER;  // and we are blind for the next cycles
      }
    }
    else if (blind > 0) {           // if we are blind, then do nothing
      blind--;							
    }
						
    if (power > flash_power) {      // if there is enough power, then we flash
      h_to_rgb(168 - nervous);      // display the color, depending on the nervous level
      _delay_ms(FLASH_DELAY);       // wait
      r = 0;                        // flash off
      g = 0;
      b = 0;                       
      power = 0;                    // reset power
      blind = BLIND_AFTER_SELF;     // blind after our own flash for some cycles
      if (nervous > 3) {            // decrease the nervous level
	nervous -= 3;
      }
    }
		
  }

  return 0;
	
}

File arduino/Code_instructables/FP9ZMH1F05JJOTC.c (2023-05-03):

/* -----------------------------------------------------------------------
 * Title:    firefly
 * Author:   Alexander Weber <alexander.weber.0 at gmail.com>
 * Date:     18.03.2007
 * Hardware: ATtiny13v
 * Software: WinAVR 20060421
 */

// define as -D switch
//#define F_CPU 1200000	// clock 1.2MHz, internal oscillator

#include <avr/io.h>
#include <avr/eeprom.h>
#include <util/delay.h>

// use PB2 for led, pin 7
#define LED_BIT 2
// use PB3 to enable ldr, pin 2
#define ADC_ENA_BIT 3
// use ADC2, PB4, pin 3
#define CHANNEL 2
// power level
#define FLASH_POWER 8000
// daylight level
#define DAY_LIGHT 500

/*
 * get_adc
 * Return the 10bit value of the selected adc channel.
 */
uint16_t get_adc(uint8_t channel) {

	uint8_t i = 0;
	uint16_t value = 0;
	
	// enable voltage for LDR
	PORTB |= (1 << ADC_ENA_BIT);	
	
	// ADC setup
	ADCSRA = 
		(1 << ADEN) |						// enable ADC
		(1 << ADPS1) | (1 << ADPS0);		// set prescaler to 8	
		
	// select channel
	ADMUX = channel;
	
	// uncomment this to select reference voltage
	// ADMUX |= (1 << REFS0);	// use internal reference

	// warm up the ADC, discard the first conversion
	ADCSRA |= (1 << ADSC);
	while (ADCSRA & (1 << ADSC)); 
	
	// do 4 conversions and take the average
	for (i = 0; i < 4; i++) {				
		ADCSRA |= (1 << ADSC);				// start single conversion
		while (ADCSRA & (1 << ADSC)); 		// wait until conversion is done
		value += ADCW;
	}
	value = value >> 2;
		
	PORTB &= ~(1 << ADC_ENA_BIT);			// disable voltage for LDR
	ADCSRA &= ~(1<<ADEN); 					// shut down the ADC
		
	return value;
}



int main(void) {	
	
	uint8_t i = 0;
	uint16_t light = 0;
	uint16_t threshold = 0;
	uint16_t power = 0;
	uint8_t blind = 0;
	
	// define LED and ADC enable as outputs
	DDRB |= (1 << LED_BIT) |
			(1 << PB0) |
			(1 <<ADC_ENA_BIT);	
			
	// set pin 0 to low
	PORTB &= ~(1 << PB0);
	
	// intro
	for (i = 0; i < 5; i++) {
		PORTB |= (1 << LED_BIT);	
		_delay_ms(200);
		PORTB &= ~(1 << LED_BIT);
		_delay_ms(200);
	}
	
	// compute threshold
	for (i = 0; i < 4; i++) {
		threshold += get_adc(CHANNEL);
		_delay_ms(200);
		_delay_ms(200);
		_delay_ms(200);
		_delay_ms(200);
		_delay_ms(200);
	}	
	threshold = threshold >> 2;
	threshold += 80;

	while (1) {	
		
		_delay_loop_1(255);
		if (power > 6000) {
			power += 1;
		}
		else if (power > 4000) {
			power += 2;
		}
		else if (power > 3000) {
			power += 4;
		}
		else if (power > 2000) {
			power += 8;
		}
		else {
			power += 16;
		}

		if (!blind) {
		    light = get_adc(CHANNEL);
		    if (light > DAY_LIGHT) {				// if there is too much light
		    	for (i = 0; i < 20; i++) {			// then sleep some seconds
		    		_delay_ms(250);
		    	}
		    }
			else if (light > threshold) {			// if there was another flash then
				power += 200;						// increase power
				blind = 100;						// and we are blind for 100 cycles
			}
		}
		else if (blind > 0) {
			blind--;							
		}
						
		if (power > FLASH_POWER) {					// if there is enough power
			PORTB |= (1 << LED_BIT);				// flash on
			_delay_ms(200);							// for 0.2 seconds
			PORTB &= ~(1 << LED_BIT);				// flash off
			power = 0;
		}
		
	}

	return 0;
	
}

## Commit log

2023-04-18 initial commit for FireFly
    [CP_Radial_D5.0mm_P2.50mm.step, CP_Radial_D6.3mm_P2.50mm.step, C_Disc_D3.0mm_W2.0mm_P2.50mm.step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]
2023-05-03 added code
    [LED_5mm_RGB.FCStd, firefly.kicad_pcb, firefly.kicad_sch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]

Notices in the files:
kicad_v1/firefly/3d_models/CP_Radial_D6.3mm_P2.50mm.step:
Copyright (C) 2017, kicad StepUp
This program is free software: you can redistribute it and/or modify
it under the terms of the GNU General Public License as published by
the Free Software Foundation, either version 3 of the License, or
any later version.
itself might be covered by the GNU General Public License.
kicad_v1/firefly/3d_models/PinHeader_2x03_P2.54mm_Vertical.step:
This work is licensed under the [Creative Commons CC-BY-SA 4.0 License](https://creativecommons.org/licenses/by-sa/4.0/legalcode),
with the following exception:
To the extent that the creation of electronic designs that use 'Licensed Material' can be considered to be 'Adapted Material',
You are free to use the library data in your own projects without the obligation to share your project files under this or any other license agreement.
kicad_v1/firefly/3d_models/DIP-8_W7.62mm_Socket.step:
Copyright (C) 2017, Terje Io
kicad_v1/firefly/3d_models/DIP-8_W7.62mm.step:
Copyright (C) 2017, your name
